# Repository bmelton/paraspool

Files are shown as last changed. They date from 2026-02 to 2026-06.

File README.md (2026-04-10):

# Paraspool

A parametric rim adapter that is designed to be filament friendly, truly universal, and to accommodate any rim size you can think of that fits into an AMS (that part is your problem.) It works well with cardboard spools, but it might work with plastic spools as well (though I've personally never had any problems with plastic spools.)

It accepts a number of arguments, but the important ones are spool_diameter, tolerance, and label_text. What's worked well for me so far is just measuring the spool with a tape measure and then trying to print that exact number, then with a tolerance of 0.4. There are 'bundles' for known good values that have printed successfully, so in Customizers, you can just select (eg) "AICOPYTO" if you're using Aicopyto spools, and it should build a good part. What I have found is that my printers are generally pretty consistent for dimensional accuracy -- my elegoo likes a tolerance of 0.05, but my Bambus like 0.04. YMMV. 

The presets here for existing spools (like Polymaker, Inland, Elegoo, etc.) have been printed and tested to work, at least on my printer. 

This relies on [Allerta Stencil](https://fonts.google.com/specimen/Allerta+Stencil) - a stencil font that is of course easy to install locally, but may not work at all on the Makerworld customizer. If you're okay with the centers of your letters falling out, this is still good. If you don't need labels, this is great - just leave the string empty.

# Printing recommendations

Layer height: 0.2 mm or 0.16 mm. Given the 1 mm wall thickness, this ensures 5–6 solid layers, which is critical for the structural integrity of the stencil bridges.

Print in PETG or above if you use your AMS heater. PLA might be fine in original AMS units. The labels are prone to stickage, so I've tried to rotate them to where my build plate is the flexiest, but an adhesion barrier might be worth doing if you're printing a bunch of them back to back.

```
outer_diameter=200
label_text = "Polymaker"; 
```
Setting diameter to '200' and text to 'Polymaker'

## License

Just a small note on licensing, but while the software assets are MIT-licensed (as shown in the LICENSE.md,) the STL artifacts are released as CC-BY. That is of course reflected by the LICENSE.md in the `assets/` folder. I only note it here because it is not necessarily obvious to look in a subfolder for a separate license, but I understand this is common in open hardware projects (I'm a noob here.)

## ROADMAP

This isn't a roadmap so much as it is a braindump of things I'd like to do in the future. 

- RFID tag support
- I really want to incorporate the eSun cardboard spools, specifically because of [this project](https://makerworld.com/en/models/1234875-reusable-cardboard-spool-ams-lite-compatible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)
- I understand that Polymaker has two sizes of spools. I've yet to encounter more than the one, which is covered, but I'd like to seek out the other.

## A note about eSun

I was originally working with redditor /u/5skinnn for eSun spools, and he noted irregularities, spool to spool. So I did the only thing that made sense to me and ordered some eSun spools for myself. Long story short, eSun is frustrating. Anyone who is telling you they've got a bulletproof eSun spool adapter is lying. 

As of this, I've added eSunLarge and an eSunSmall assets, representing the biggest range I've encountered, but eSun spools are remarkably un-uniform. I printed a spool at 200.5mm and it fits *perfectly* on my eSun spool. I hit 'Print again' for the other size, and it slips right off. On one single eSun spool, the outer diameter variance is more than 1mm from one side to the other. 

I'm including them as a starting point, but nobody should rely on them. If you have one of each outer diameter, you'll probably have one to fit an eSun spool.   

## Coverage

This list is almost certainly not exhaustive, but it's every reputable brand I know about. Feel free to add a PR for any additional spools, *particularly* those that are cardboard. 

- [ ] 3DJake
- [ ] 3DHoJor
- [x] AICOPYTO
- [ ] Anycubic
- [ ] Azurefilm
- [ ] CC3D
- [ ] Creality
- [x] DEEPLEE
- [ ] Duramic
- [x] Elegoo
- [ ] Eryone
- [x] eSun
- [ ] FormFutura
- [x] Inland
- [ ] Justmaker
- [ ] Landu
- [ ] Matter3D
- [ ] NextShapes
- [x] Overture
- [x] OVV3D
- [x] Polymaker PanChroma / PolyTerra
- [ ] Polymaker PolyLite
- [ ] Polymaker PolyMax / PolySonic / Draft (I believe these are all the same spool)
- [ ] PrintedSolid
- [ ] ProtoPasta
- [ ] SainSmart

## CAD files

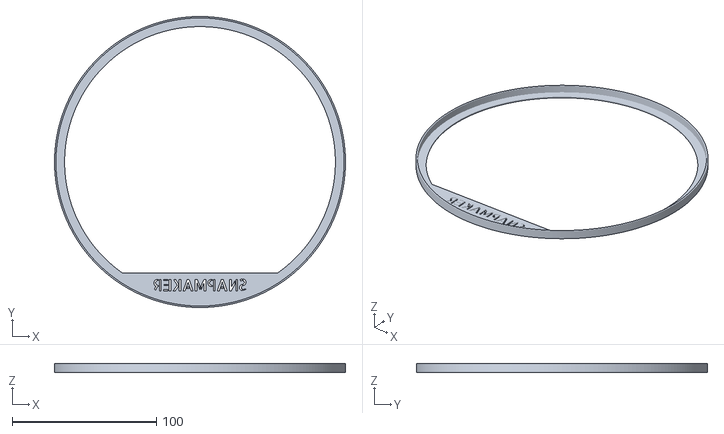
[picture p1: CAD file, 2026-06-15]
assets/snapmaker.stl
201.4 x 201.4 x 6.00

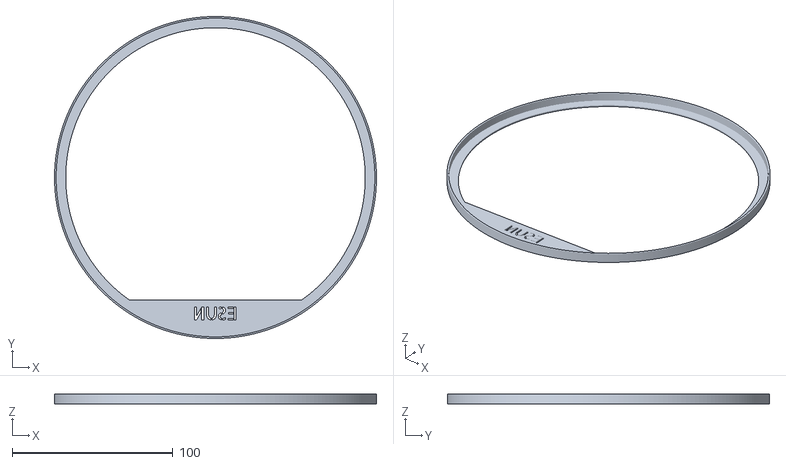
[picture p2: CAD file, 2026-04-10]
assets/eSunSmall.stl
200.4 x 200.4 x 6.00

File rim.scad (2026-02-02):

// An actually universal spool rim adapter.
/* [parameters] */
// outer diameter of the spool rim
outer_diameter = 200; 
// text to be cut out of the nameplate. Leave blank to omit nameplate. Set to one space for an empty nameplate.
label_text = "Polymaker"; 

// width of the horizontal rim face, in mm
rim_width = 6; 
// height of the vertical lip face, in mm
lip_height = 6; 

// thickness of the L-profile walls, in mm
wall_thickness = 1; 

// font size for the label
font_size = 8;

// how far the plate extends from the inner edge toward the center
plate_depth = 17;
// font "Allerta Stencil" or another stencil font is needed
font = "Allerta Stencil:style=Regular";

/* [hidden] */  
$fn = 200;
inner_diameter = outer_diameter - (rim_width * 2);

module l_profile_ring() {
    union() {
        // horizontal face (rim)
        linear_extrude(wall_thickness)
            difference() {
                circle(d = outer_diameter);
                circle(d = inner_diameter);
            }
        
        // vertical face (lip)
        linear_extrude(lip_height)
            difference() {
                circle(d = outer_diameter);
                circle(d = outer_diameter - (wall_thickness * 2));
            }
    }
}

module nameplate_stencil() {
    infinite_width = outer_diameter;
    
    difference() {
        // 1. the shelf geometry (clipped to circle)
        intersection() {
            linear_extrude(wall_thickness)
                translate([-infinite_width/2, -(inner_diameter/2), 0])
                    square([infinite_width, plate_depth]);
            
            linear_extrude(wall_thickness)
                circle(d = inner_diameter);
        }
        
        // 2. the text cutout (stencil) with mirror fix
        if (label_text != "") {
            translate([0, -(inner_diameter/2) + (plate_depth/2), -1]) 
                linear_extrude(wall_thickness + 2) 
                    mirror([1, 0, 0]) // reverses text direction
                        text(label_text, size = font_size, halign = "center", valign = "center", font = font);
        }
    }
}

// assembly
l_profile_ring();
if (label_text != "") {
    nameplate_stencil();
}

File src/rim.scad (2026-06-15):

// An actually universal cardboard spool rim adapter for AMSes.

/* [Preset Selection] */
// Select your spool brand. Choose "Custom" to use manual settings below.
spool_type = "AICOPYTO"; // [AICOPYTO, DEEPLEE, eSunSmall, eSunLarge, Elegoo, Inland, Overture, OVV3D, Polymaker, Snapmaker, Sunlu, Custom]

/* [Manual Settings] */
// Only used if spool_type is "Custom". Diameter of the cardboard spool.
manual_spool_diameter = 200;

// Only used if spool_type is "Custom". Text to be cut out.
manual_label_text = "CUSTOM";

/* [General Parameters] */
// Extra clearance so the adapter slides on easily
tolerance = 0.4;

// Width of the horizontal rim face
rim_width = 6;

// Height of the vertical lip face
lip_height = 6;

// Thickness of the L-profile walls
wall_thickness = 1;

// Font size for the label
font_size = 8;

// How far the plate extends from the inner edge toward the center
plate_depth = 17;

// Font: If you don't use a stencil font, the center of your letters will fall out. It's not a problem really, but be warned.
font = "Allerta Stencil:style=Regular";

/* [hidden] */
$fn = 200;

// PRESETS
// Units: 196mm (7.72"), 200mm (7.87")

// 1. Determine Diameter
spool_diameter = 
    (spool_type == "AICOPYTO") ? 193 : 
    (spool_type == "DEEPLEE") ? 195.8 :
    (spool_type == "eSunSmall") ? 198 :
    (spool_type == "Elegoo")   ? 199 : 
    (spool_type == "Inland")   ? 199 : 
    (spool_type == "OVV3D")    ? 199 :
    (spool_type == "Overture") ? 199.5 :
    (spool_type == "Polymaker") ? 199.5 :  
    (spool_type == "Sunlu") ? 199.5 :
    (spool_type == "Snapmaker") ? 199.5 :
    (spool_type == "eSunLarge") ? 200.5 :
    manual_spool_diameter;             // defaults to custom

// 2. Determine Label
label_text = 
    (spool_type == "AICOPYTO") ? "AICOPYTO" : 
    (spool_type == "DEEPLEE") ? "DEEPLEE" :
    (spool_type == "Elegoo")   ? "ELEGOO" : 
    (spool_type == "Inland")   ? "INLAND" : 
    (spool_type == "OVV3D")    ? "OVV3D" :
    (spool_type == "Overture") ? "OVERTURE" :
    (spool_type == "Polymaker") ? "POLYMAKER" :
    (spool_type == "Sunlu") ? "SUNLU" :
    (spool_type == "Snapmaker") ? "SNAPMAKER" :
    (spool_type == "eSunSmall") ? "ESUN" :
    (spool_type == "eSunLarge") ? "ESUN" :

    manual_label_text;                 // defaults to custom

// Calculated dimensions
// lip_inner_diameter: spool_diameter + tolerance
// 196mm + 0.2mm = 196.2mm (7.724")
lip_inner_diameter = spool_diameter + tolerance;
lip_outer_diameter = lip_inner_diameter + (wall_thickness * 2);
center_hole_diameter = lip_inner_diameter - (rim_width * 2);

module l_profile_ring() {
    union() {
        // horizontal face (rim)
        linear_extrude(wall_thickness)
            difference() {
                circle(d = lip_outer_diameter);
                circle(d = center_hole_diameter);
            }

        // vertical face (lip)
        linear_extrude(lip_height)
            difference() {
                circle(d = lip_outer_diameter);
                circle(d = lip_inner_diameter);
            }
    }
}

module nameplate_stencil() {
    infinite_width = lip_outer_diameter;

    difference() {
        intersection() {
            linear_extrude(wall_thickness)
                translate([-infinite_width/2, -(center_hole_diameter/2), 0])
                    square([infinite_width, plate_depth]);

            linear_extrude(wall_thickness)
                circle(d = center_hole_diameter);
        }

        if (label_text != "") {
            translate([0, -(center_hole_diameter/2) + (plate_depth/2), -1])
                linear_extrude(wall_thickness + 2)
                    mirror([1, 0, 0]) 
                        text(label_text, size = font_size, halign = "center", valign = "center", font = font);
        }
    }
}

// assembly
l_profile_ring();
if (label_text != "") {
    nameplate_stencil();
}

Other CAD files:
assets/ovv3d.stl
assets/eSunLarge.stl
assets/deeplee.stl
assets/sunlu.stl
assets/polymaker.stl
assets/elegoo.stl
assets/aicopyto.stl

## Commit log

2026-02-02 Working (I think)
    [rim.scad]
2026-02-10 Structuring the project a little bit.
    [aicopyto.stl, elegoo.stl, rim.scad]
2026-02-11 Fixes polymaker asset. Adds Deeplee, Sunlu. Adds roadmap.
    [deeplee.stl, polymaker.stl, rim.scad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]
2026-03-12 Add eSun rim
    Measurements contributed by /u/5skinnn on reddit
    [rim.scad]
2026-04-10 Adds a second eSun variant.
    [eSunLarge.stl, eSunSmall.stl, rim.scad]
2026-06-13 Adds OVV3D.
    [rim.scad]
2026-06-13 Adds rendered STL for OVV3D.
    [ovv3d.stl]
2026-06-14 Adds Snapmaker option and rendered asset.
    [rim.scad, snapmaker.stl]
2026-06-15 Was too tight. And duh, Snapmaker spool is just Polymaker spool.
    [rim.scad]
